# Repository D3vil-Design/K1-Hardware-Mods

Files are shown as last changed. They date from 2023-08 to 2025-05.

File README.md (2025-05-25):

# D3D K1 Hardware Modifications

This repository is dedicated to providing a centralized location to the hardware modifications that the D3vil Design team has created for the Creality K1 and K1 Max.

If you would like to support the team to fund future projects, you can visit us at our [Patreon](https://www.patreon.com/D3vilDesign). Thank you.

A tutorial for some of the WIP things here can be found at one of our D3vil Design team member's YouTube channel, Omranello: https://www.youtube.com/@omranello. Otherwise, **please refer to the respective README in each mod's folder.**

All work in this repository falls under the **Attribution-NonCommercial-ShareAlike 4.0 International (CC BY-NC-SA 4.0)** license unless mentioned otherwise.

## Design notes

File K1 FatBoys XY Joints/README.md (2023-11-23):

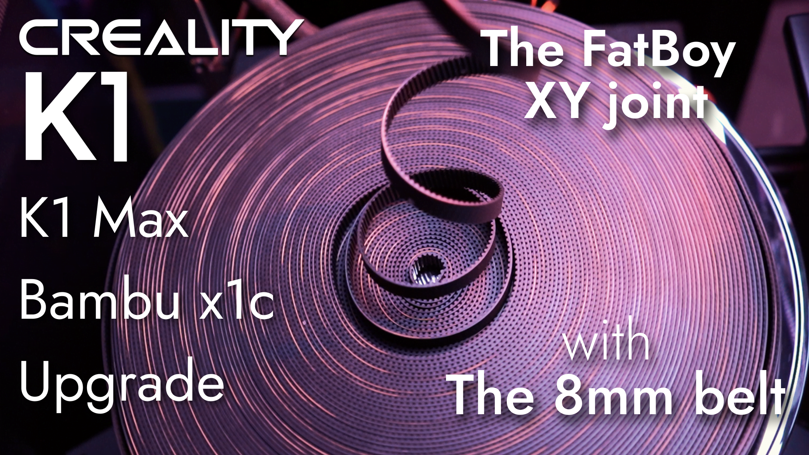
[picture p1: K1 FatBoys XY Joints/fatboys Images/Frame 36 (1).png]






Kindly if you dont know what you are doing , ask in our [Discord](https://discord.gg/d3vil-design) server

This joint are bigger by 5mm in both side which means it will reduce the overall X movment in the gantry on the K1 from 235 to 225 ( same build size ) 
- they can be used with the stock idlers ( if you are using the 8mm belt )
- or it can be used with any other 6mm idlers aswell.

Be advised to use the same M5x5mm grub screw to hold the rods in place instead of glue. (DO NOT OVERTIGHTEN)

changes might be needed to the printer.cfg file

For the K1:

change the [stepper_x] values below:

position_endstop: 226  ##stock value was 229

position_min: 0        ##stock value was -5

position_max: 226      ##stock value was 229

NOTE: the idea is to move you toolhead to X=10 and test move it from there 1mm at a time to see where the x carriage will touch the left XY joint.

For the K1 Max:

Needs to bee tested step by step ... will be updated

This will be updated soon™️

special thanks to all the ones who tested it and reported thier findings 

If you would like to support the team to fund future projects, you can visit us at our [Patreon](https://www.patreon.com/D3vilDesign).

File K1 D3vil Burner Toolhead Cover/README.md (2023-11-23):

# D3D K1 D3vil Burner V3

**The long awaited D3vil Burner by the D3D team, featuring Knomi support, is here!**

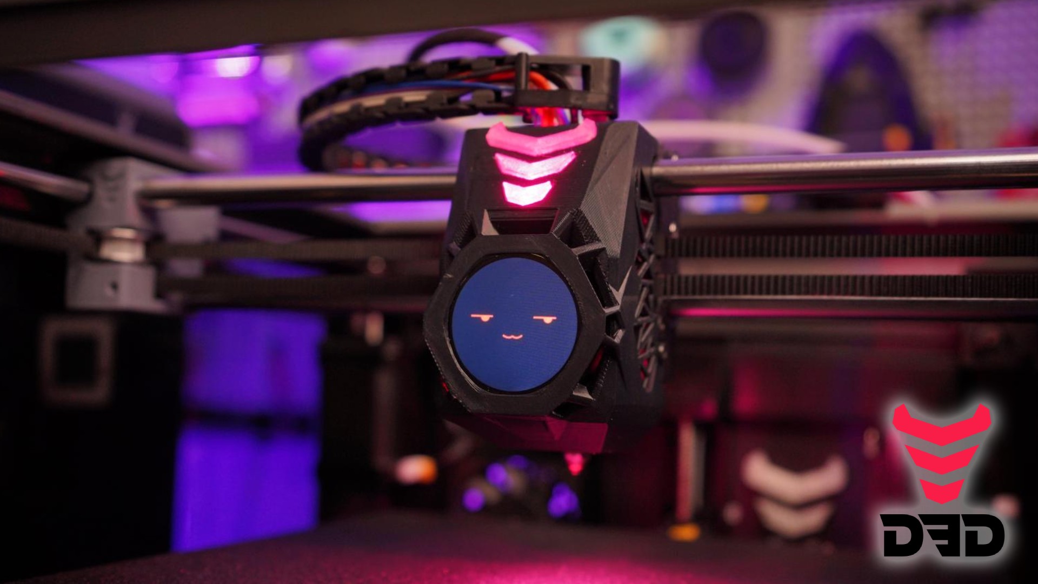
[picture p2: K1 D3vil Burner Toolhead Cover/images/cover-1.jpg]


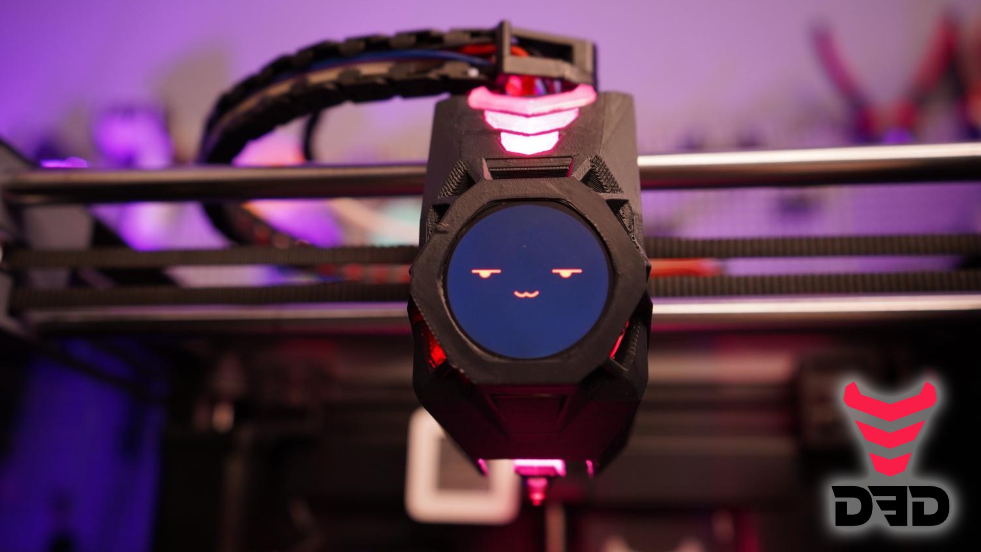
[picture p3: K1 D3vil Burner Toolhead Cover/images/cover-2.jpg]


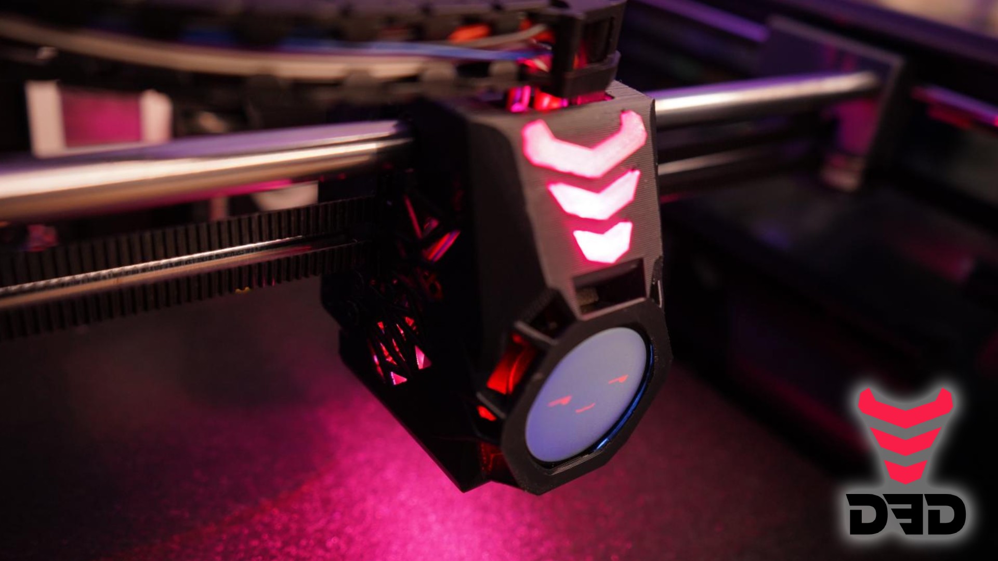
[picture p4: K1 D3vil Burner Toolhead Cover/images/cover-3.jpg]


## Introduction

D3vil Design is proud to release the D3vil Burner toolhead cover for the Creality K1 for **free**. Packed with features, the team has worked meticulously to make sure that the cover is ready for release and as easy as a drop-in as possible with the limited space in the stock Creality K1 toolhead setup.

## Features

- Drop in replacement for the Creality K1 - no permenant modifications!
- Full Knomi support - view print progress real time, and add a little flair to your toolhead!
- Customizable LED featuring the D3vil Design logo - use any LED to match the style of your setup!
- Lightweight - 3.5 grams **LIGHTER** than the stock toolhead! (tests using ASA/ABS+, stock K1 shroud at 23.8 grams, D3vil Burner printed in ASA is 20.3 grams)

## Support

Join our [Discord](https://discord.gg/d3vil-design) to chat with the team and find support for this product and anything else that D3D puts out :)

## Knomi 

for those who asked, you can purchase Knomi directly from the (non affiliate) link below 
https://biqu.equipment/collections/lcd/products/bigtreetech-knomi-v1-0

## Installation Guide

1. Download and print both STLs in this folder - the toolhead cover and the D3D logo. Recommended print settings for each are as follows:

   ##### D3vil Burner Toolhead Cover

   - Material: ABS, ASA, or another heat-resistant material
   - Layer Height: 0.2
   - Line width: 0.4
   - Walls: 3
   - Top/Bottom Layers: 3
   - Supports required (Top Z distance somewhere around 0.15)
   - orientation: print it facing up for the best results. 
   - Color: Your Choice!

   ##### D3vil Burner D3D Logo

   - Material: ABS, ASA, PETG, or another heat-resistant material
   - Layer Height: 0.2
   - Line width: 0.4
   - Walls: 3
   - Top/Bottom Layers: 3
   - Supports required (Top Z distance somewhere around 0.15)
   - Color: White or Transparent (we want light to shine through)

2. Remove the two screws from the stock toolhead cover and slide the cover off
3. Disconnect the front fan from the toolhead board and remove the fan from the stock toolhead cover
4. Slide the D3D Logo piece into the slot on the new toolhead's slot.
5. Connect a wire to the Knomi:

   ##### If you're not using an LED:

   5a. Find or create an MX1.25 (2pin) to MX1.25 (3pin) wire. Red to red, black to black according to the pinout shown on the board itself (Red to V and Black to G). We won't use the 3rd pin - this is just so we can connect it easily.

   5b. Connect the MX1.25 2pin to the Knomi **AND GENTLY PRY OFF THE USB PORT FROM THE KNOMI. IT DOES NOT FIT IN A STOCK SETUP**, then GENTLY (do not force, you'll crack the screen!) slide the Knomi into it's place from the back in.

   ##### If you are using an LED:

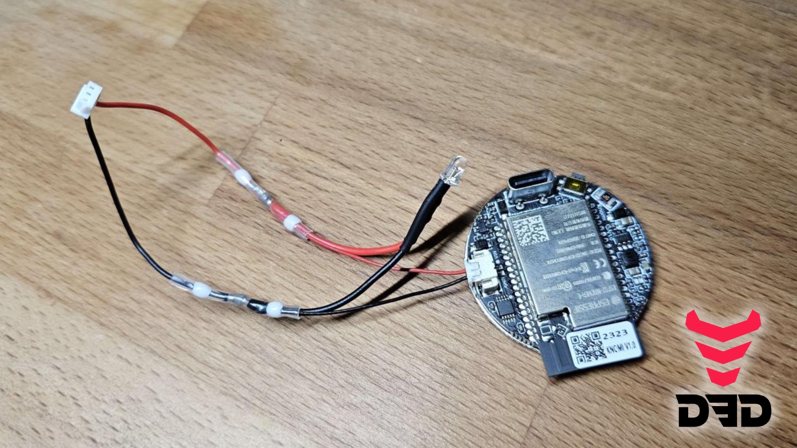
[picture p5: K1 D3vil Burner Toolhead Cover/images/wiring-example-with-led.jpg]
   

   5a. Create a three-way wire. This wire should be an MX1.25 (2pin) to MX1.25 (3pin) to V/G (whatever your LED needs) wire. Red to red to read, black to black to black according to the pinout shown on the board itself (Red to V and Black to G). We won't use the 3rd pin - this is just so we can connect it easily.

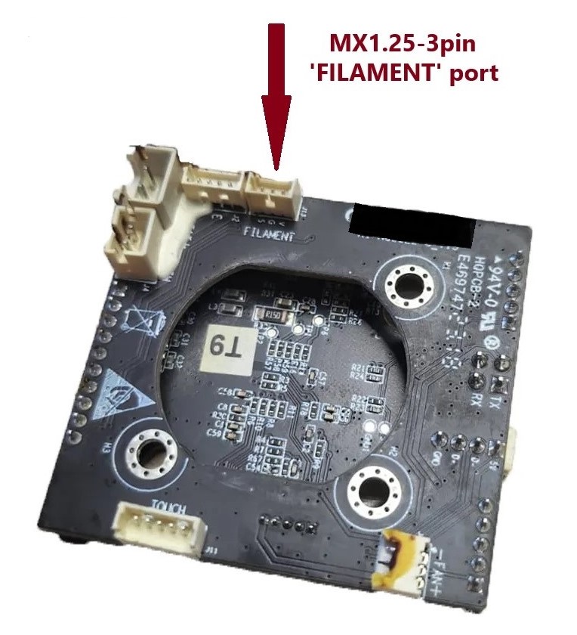
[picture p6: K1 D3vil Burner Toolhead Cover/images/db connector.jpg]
    

   5b. Solder or attach your V/G to your LED - the voltage is 5V coming from the toolboard - make sure your LED supports this or use a resistor.

   5c. There are two slots where you can lay your wires to prop up the LED. Attach those and prop your LED against the D3D logo piece.

   5d. Connect the MX1.25 2pin to the Knomi **AND GENTLY PRY OFF THE USB PORT FROM THE KNOMI. IT DOES NOT FIT IN A STOCK SETUP**, then GENTLY (do not force, you'll crack the screen!) slide the Knomi into it's place from the back in.

7. Slide the fan against the Knomi and attach the fan using the stock screws.
8. Connect the other end of the Knomi wire to the free filament sensor port on the toolhead board (again, outlined on the pinout shown on the board, Red to V and Black to G).
9. Re-attach the fan wire to the toolhead board.
10. Slide the D3vil Burner on to the toolhead and re-attach using the stock screws.
11. Voíla! Re-run input shaping, connect your Knomi following [BTT's instructions](https://github.com/bigtreetech/KNOMI/blob/master/KNOMI_USER_GUIDE.pdf).
12. NOTE: When connecting to Knomi Via wifi, in the setup screen, you will have to Add the IP address of your Printer ( Since this only works with Rooted Printers ) you will have to add the IP and the Port (ex: 192.168.1.10:4408 ).

And you're set!

If you would like to support the team to fund future projects, you can visit us at our [Patreon](https://www.patreon.com/D3vilDesign). We will begin posting behind the scenes projects, beta access to projects in flight, and more exclusively for our [Patreon](https://www.patreon.com/D3vilDesign) supporters.

-----------
If you wish to activate the Homing Macro please check the update below 

Thanks to [nephilim667](https://github.com/nephilim667)

[Homing macro fix](https://github.com/D3vil-Design/K1-Hardware-Mods/issues/4)

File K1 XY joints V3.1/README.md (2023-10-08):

# D3D K1 XY Joint V3.3 "Updated"

## NOTE:
YOU NEED TO REPRINT XY joint V3.3DD both right and left STL files since V3.1 had some tolerances issues .

# D3D K1 XY Joint V3.1

**This is a work in progress.**

To see how this was made and used, please watch the following video:

https://youtu.be/I9yJWq1kYok

This design was made to change the idlers in the K1 to a 6mm x 4mm bore or keep the original ones. For the idlers, we removed the pins and installed BHCS or SHCS M4x20mm... 18mm can also be used.

(Note in the setup shown above, we used M4x20 grub screws instead of a SHCS or BHCS) For the X axis rods, I used M5x5mm grub screws.

## print 

- ABS+,ASA ... OR WHAT U SEE FIT 
- 4 walls
- 4 bottom layers , 4 top layers
- 40% infill triangle
- orientation: Face(logo) down .
- with support

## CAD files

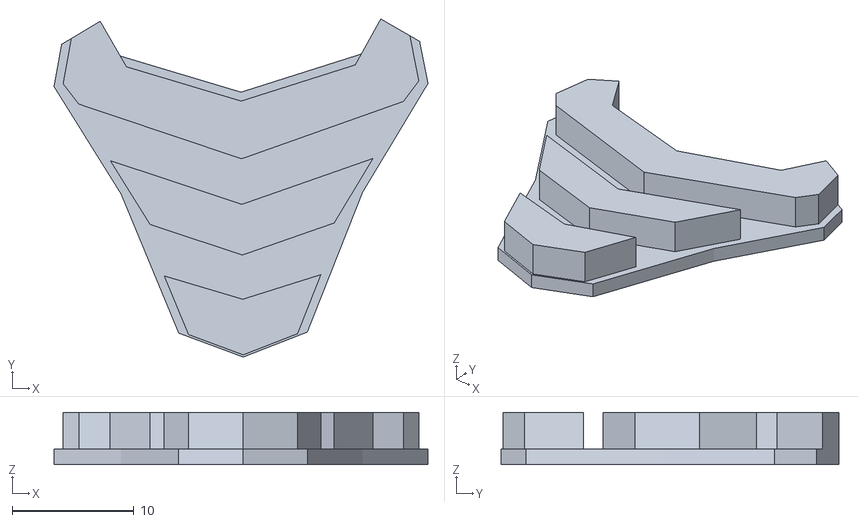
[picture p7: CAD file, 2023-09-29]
K1 D3vil Burner Toolhead Cover/K1 D3vil Burner Logo V3 (D3D).stl
30.8 x 27.8 x 4.30

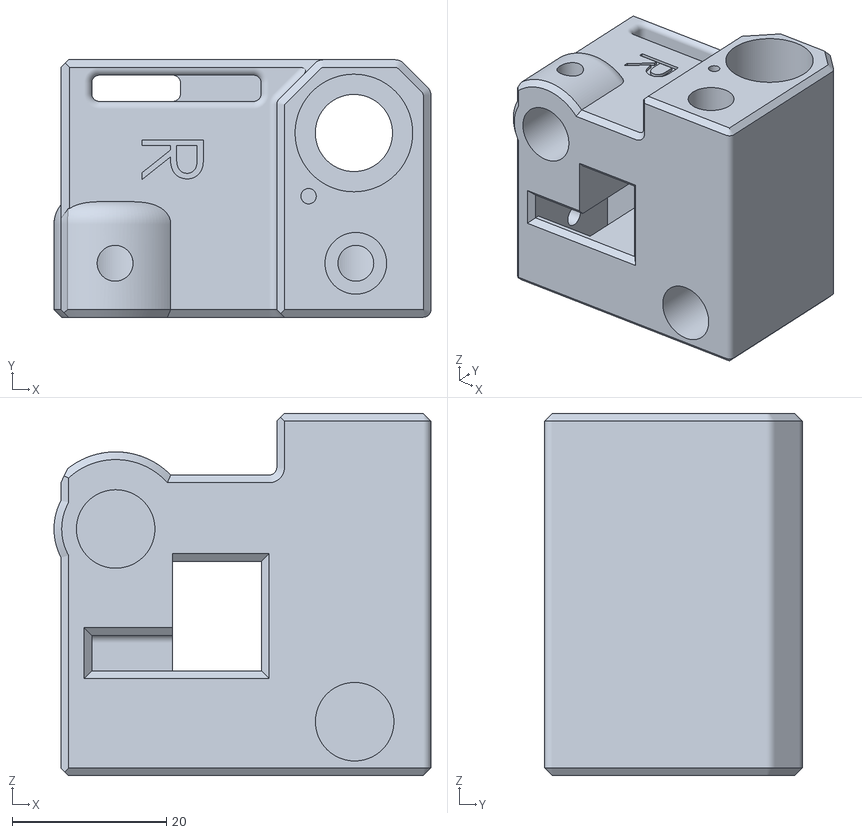
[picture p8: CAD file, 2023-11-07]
K1 FatBoys XY Joints/FatBoy XY joint R.stl
48.9 x 33.4 x 47.0

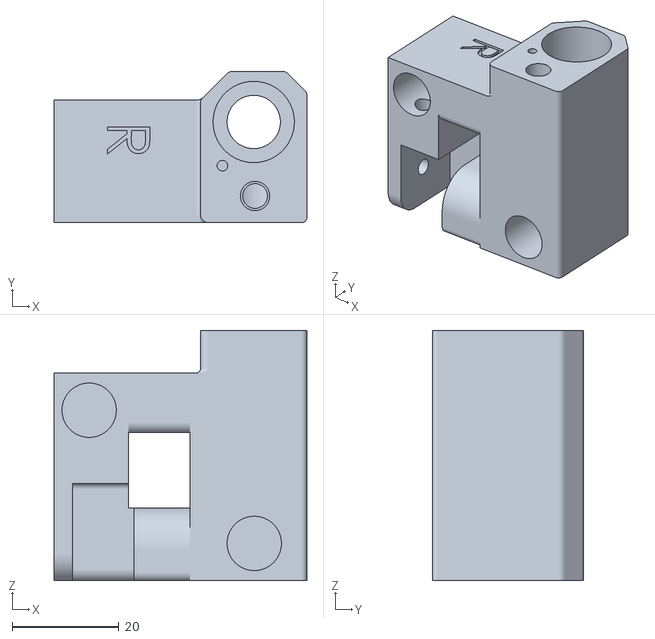
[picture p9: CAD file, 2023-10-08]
K1 XY joints V3.1/Right XY joint v3.3DD.stl
47.5 x 28.4 x 47.0

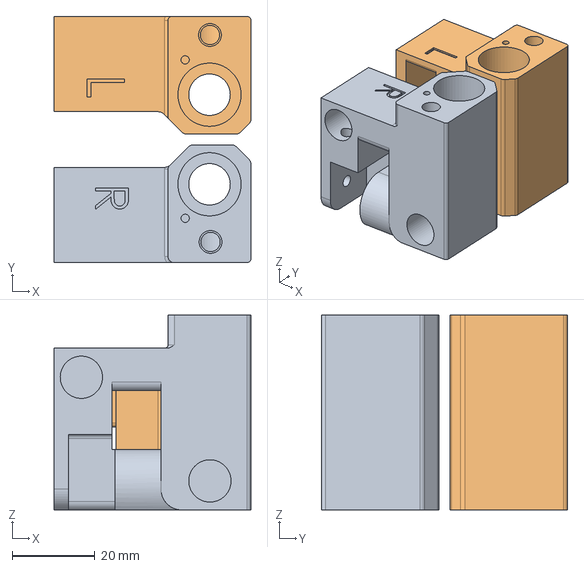
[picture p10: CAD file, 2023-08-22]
K1 XY joints V3.1/K1 XY JOINT V3 (D3D).step
47.5 x 59.4 x 47.0 mm
XY_joint_Right.STEP
XY_joint_Left.STEP

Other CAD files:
K1 FatBoys XY Joints/FatBoy XY joint L.stl
K1 XY joints V3.1/Left XY joint v3.3DD.stl
K1 XY joints V3.1/K1 XY Joint V3 (D3D).3mf

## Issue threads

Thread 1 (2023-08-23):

"k1 xy joint v3.1.3mf" being flagged as Archive.Bomb by Baidu in VirusTotal

Su-Plx, 2023-08-23:
Hi Omran!

First off, thank you so much for all the assistance you've been offering the K1 community---I know that I, and a lot of other folks who have bought one, have honestly felt more supported and seen in the tutorial and mod videos that you've made, than by the support offered from Creality themselves. It can often be thankless, and dealing with Creality can be incredibly frustrating, so I want you to know that, at least for me, your videos are the ones I go to first whenever I'm having trouble with the printer, need to remember how something was put together, get ideas for improvements, etc.. And the music isn't bad, either 😎️👍️

The work you've put into refining the movement system is the first major step forward into making the K1 a truly consistent and reliable print platform. Thank you so much!

I wanted to give you a heads up that for whatever reason, Baidu via VirusTotal is flagging the file "k1 xy joint v3.1.3mf" as an archive/zip bomb. I grabbed a couple random 3mf files from Printables with a similar size/number of compressed files, and scanned them to see if Baidu was flagging all 3mf files, but I only saw that behavior from the 3mf I got from your github repo.

I don't think it is intentional, and haven't flagged or reported the file to github or anything. My guess is that the easiest fix might be to try repacking the model into a new 3mf and re-uploading, but I'm not set up to test that sort of thing, so I can't say for sure.

Thank you again for the incredible help you've been to the K1 community!

-Su_Plx

Omranello, 2023-08-23:
Bro thanks alot for the sweet email , this worth it all.

I will upload the STL instead .. it's better I guess.

Thanks for the heads up,  I would not have noticed it myself.

If anything I can help u with please contact me ... always here to help .

Thanks again

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

Omranello, 2023-10-09:
New files uploaded .

Closed 2023-10-09.

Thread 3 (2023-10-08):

knomi issues

kwotattoos, 2023-10-08:
in the read me it says to follow btt info for the knomi but the required macro gave me errors and locked up my homing. what should we add to get the knomi to show all the different animations?

Omranello, 2023-10-09:
> in the read me it says to follow btt info for the knomi but the required macro gave me errors and locked up my homing. what should we add to get the knomi to show all the different animations?

The Macros are not needed , (only for homing and leveling animation /information)
Once the Knomi is linked fine wifi thro the Hello screen by adding the ( IP address: port ) all should work fine.

lvlacleod, 2023-10-09:
> in the read me it says to follow btt info for the knomi but the required macro gave me errors and locked up my homing. what should we add to get the knomi to show all the different animations?

To get Homing and bed mesh working follow this. Took me a while to figure it all out but finally got both homing and bed mesh working with knomi.
https://github.com/bigtreetech/KNOMI/pull/5

Omranello, 2023-11-01:
Thank you , ill go ahead and close this as we will add it to the main page

Closed 2023-11-01.

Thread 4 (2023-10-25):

Macro integration for Homing and Leveling

nephilim667, 2023-10-25:
Hello,

I have integrated a Knomi from BigTreeTech with your D3vil design head mount.

Actually in Knomi documentation they tell to add relevant macros for homing and bed leveling.
Unfortunatly those macro aren't working on K1 !

After some research i have finally make it work.

for homing, if you put macro as it, it will throw an error 'G28 is called recursively'.
I have found that come from macro defined in sensorless.cfg

So to make it work, first add the macro at end of file
`[gcode_macro G28]`
`rename_existing: G0028`
`variable_homing:False`
`gcode:`
`  RESPOND TYPE=command MSG='Custom G28 called'`
`  SET_GCODE_VARIABLE MACRO=G28 VARIABLE=homing VALUE=True`
`  G0028 {rawparams}`
`  SET_GCODE_VARIABLE MACRO=G28 VARIABLE=homing VALUE=False`

atfer what find _HOME_X, _HOME_Y and _HOME_Z macro and replace G28 in it by G0028 like this
`[gcode_macro _HOME_X]`
`gcode:`
`  _IF_MOVE_XY`
`  {% if printer['gcode_macro xyz_ready'].x_ready|int == 1 %}`
`    {% if (printer.configfile.settings['stepper_x'].position_max - printer.toolhead.position.x)|round < 10 %}`
`      {% set x_park = (10 - (printer.configfile.settings['stepper_x'].position_max - printer.toolhead.position.x))|round %}`
`      {% if x_park > 0 %}`
`        G91`
 `       G1 x-{x_park} F3600`
`        G90`
`        G4 P1000`
`      {% endif %}`
`    {% endif %}`
`  {% endif %}`
`  `
`# SET_TMC_FIELD FIELD=SGTHRS STEPPER=stepper_y VALUE=70`
`# SET_TMC_FIELD FIELD=SGTHRS STEPPER=stepper_x VALUE=70`
`# Home`
`  RESPOND TYPE=command MSG='Call G28 in _HOME_X macro'`
`  G0028 X #<<====== HERE`
`  SET_GCODE_VARIABLE MACRO=xyz_ready VARIABLE=x_ready VALUE=1`
`# Move away`
`  G91`
`  G1 x-10 F3600`
`  G90`
`# Wait just a second (give StallGuard registers time to clear)`
` G4 P2000`

For bed leveling, as i'm using Kamp, in Adaptative_Meshing.cfg, BED_MESH_CALIBRATE Macro is already defined
So just add  "variable_probing:False" after rename existing and SET_GCODE_VARIABLE before and after calling _BED_MESH_CALIBRATE

Here is the modified macro :
`[gcode_macro BED_MESH_CALIBRATE]`
`rename_existing: _BED_MESH_CALIBRATE`
`variable_probing:False`
`gcode:`

    {% set all_points = printer.exclude_object.objects | map(attribute='polygon') | sum(start=[]) %}                                # Gather all object points
    {% set bed_mesh_min = printer.configfile.settings.bed_mesh.mesh_min %}                                                          # Get bed mesh min from printer.cfg
    {% set bed_mesh_max = printer.configfile.settings.bed_mesh.mesh_max %}                                                          # Get bed mesh max from printer.cfg
    {% set probe_count = printer.configfile.settings.bed_mesh.probe_count %}                                                        # Get probe count from printer.cfg
    {% set kamp_settings = printer["gcode_macro _KAMP_Settings"] %}                                                                 # Pull variables from _KAMP_Settings
    {% set verbose_enable = kamp_settings.verbose_enable | abs %}                                                                   # Pull verbose setting from _KAMP_Settings
    {% set probe_dock_enable = kamp_settings.probe_dock_enable | abs %}                                                             # Pull probe dockable probe settings from _KAMP_Settings
    {% set attach_macro = kamp_settings.attach_macro | string %}                                                                    # Pull attach probe command from _KAMP_Settings
    {% set detach_macro = kamp_settings.detach_macro | string %}                                                                    # Pull detach probe command from _KAMP_Settings
    {% set mesh_margin = kamp_settings.mesh_margin | float %}                                                                       # Pull mesh margin setting from _KAMP_Settings
    {% set fuzz_amount = kamp_settings.fuzz_amount | float %}                                                                       # Pull fuzz amount setting from _KAMP_Settings
    {% set probe_count = probe_count if probe_count|length > 1 else probe_count * 2  %}                                             # If probe count is only a single number, convert it to 2. E.g. probe_count:7 = 7,7
    {% set max_probe_point_distance_x = ( bed_mesh_max[0] - bed_mesh_min[0] ) / (probe_count[0] - 1)  %}                            # Determine max probe point distance
    {% set max_probe_point_distance_y = ( bed_mesh_max[1] - bed_mesh_min[1] ) / (probe_count[1] - 1)  %}                            # Determine max probe point distance
    {% set x_min = all_points | map(attribute=0) | min | default(bed_mesh_min[0]) %}                                                # Set x_min from smallest object x point
    {% set y_min = all_points | map(attribute=1) | min | default(bed_mesh_min[1]) %}                                                # Set y_min from smallest object y point
    {% set x_max = all_points | map(attribute=0) | max | default(bed_mesh_max[0]) %}                                                # Set x_max from largest object x point
    {% set y_max = all_points | map(attribute=1) | max | default(bed_mesh_max[1]) %}                                                # Set y_max from largest object y point

    {% set fuzz_range = range((0) | int, (fuzz_amount * 100) | int + 1) %}                                                          # Set fuzz_range between 0 and fuzz_amount
    {% set adapted_x_min = x_min - mesh_margin - (fuzz_range | random / 100.0) %}                                                   # Adapt x_min to margin and fuzz constraints
    {% set adapted_y_min = y_min - mesh_margin - (fuzz_range | random / 100.0) %}                                                   # Adapt y_min to margin and fuzz constraints
    {% set adapted_x_max = x_max + mesh_margin + (fuzz_range | random / 100.0) %}                                                   # Adapt x_max to margin and fuzz constraints
    {% set adapted_y_max = y_max + mesh_margin + (fuzz_range | random / 100.0) %}                                                   # Adapt y_max to margin and fuzz constraints

    {% set adapted_x_min = [adapted_x_min , bed_mesh_min[0]] | max %}                                                               # Compare adjustments to defaults and choose max
    {% set adapted_y_min = [adapted_y_min , bed_mesh_min[1]] | max %}                                                               # Compare adjustments to defaults and choose max
    {% set adapted_x_max = [adapted_x_max , bed_mesh_max[0]] | min %}                                                               # Compare adjustments to defaults and choose min
    {% set adapted_y_max = [adapted_y_max , bed_mesh_max[1]] | min %}                                                               # Compare adjustments to defaults and choose min

    {% set points_x = (((adapted_x_max - adapted_x_min) / max_probe_point_distance_x) | round(method='ceil') | int) + 1 %}          # Define probe_count's x point count and round up
    {% set points_y = (((adapted_y_max - adapted_y_min) / max_probe_point_distance_y) | round(method='ceil') | int) + 1 %}          # Define probe_count's y point count and round up

    {% if (points_x > points_y) %}
        {% set points_y = points_x %}
    {% endif %}

    {% if (points_x < points_y) %}
        {% set points_x = points_y %}
    {% endif %}

    {% if (([points_x, points_y]|max) > 6) %}                                                                                       #
        {% set algorithm = "bicubic" %}                                                                                             #
        {% set min_points = 4 %}                                                                                                    #
    {% else %}                                                                                                                      # Calculate if algorithm should be bicubic or lagrange
        {% set algorithm = "lagrange" %}                                                                                            #
        {% set min_points = 3 %}                                                                                                    #
    {% endif %}                                                                                                                     #

    {% set points_x = [points_x , min_points]|max %}                                                                                # Set probe_count's x points to fit the calculated algorithm
    {% set points_y = [points_y , min_points]|max %}                                                                                # Set probe_count's y points to fit the calculated algorithm
    {% set points_x = [points_x , probe_count[0]]|min %}
    {% set points_y = [points_y , probe_count[1]]|min %}

    {% if verbose_enable == True %}                                                                                                 # If verbose is enabled, print information about KAMP's calculations
        {% if printer.exclude_object.objects != [] %}

            { action_respond_info( "Algorithm: {}.".format(                                                                      
                (algorithm),                                                                                                    
            )) }

            { action_respond_info("Default probe count: {},{}.".format(                                                          
                (probe_count[0]),                                                                                               
                (probe_count[1]),                                                                                               
            )) }

            { action_respond_info("Adapted probe count: {},{}.".format(                                                          
                (points_x),                                                                                                     
                (points_y),                                                                                                     
            )) }
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
Omranello, 2023-10-25:
Someone reported the Same , thanks for sharing , will try to test it and update the page . 🙏

nephilim667, 2023-10-26:
you're welcome !
thanks to you to share your awesome desing to integrate a knomi on K1 !

Omranello, 2023-11-01:
ill go ahead and close this, and will try to add your code to the main page. Thanks again.

Nazgile94, 2023-11-25:
worked, thanks!

Galv87, 2023-12-17:
my Kamp files are read only so i can't add the homing, is anyone else having this issue?

nephilim667, 2023-12-17:
yes, since guillouz have change the script and make Kamp file readonly, you have to edit in in SSH mode with nano in sudo mode.

Galv87, 2023-12-17:
> yes, since guillouz have change the script and make Kamp file readonly, you have to edit in in SSH mode with nano in sudo mode.

what's the initial code to put into terminal (I'm a noob with terminal) ill that edit the file to take it out of read only?

nephilim667, 2023-12-20:
you can find an help guide i have made here
https://docs.google.com/document/d/13aPvhx-T9cJWjTx8hVB9-xSNzAWho6zwdE2oVVuJMIU/edit?usp=drive_link

this guide is to help with Guillouz script, but at the end you will find the integration of knomi macro with nano.
Hope this can help

Barconero, 2024-09-21:
Hi!

Is this mean, that we do not need to change Adaptative_Meshing.cfg at all, evrything is done in knomi.cfg, yes?

Closed 2023-11-01.

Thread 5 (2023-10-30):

Bearings

bronsn, 2023-10-30:
Hello,
great work from you and your Team/Partner what ever , glad that you give us such good impressions and information about the K1.
I have damaged my Bearing above the big idler over the Stepper motor , so i stopped the work and put the damaged back (he works but i think he will break soon ), do you know wich bearings are there in or which number they have ?

Other i have to disamble the printer again before i can purchase some new one.
Sry i know this is not the Issue with your design as itself, but perhaps you can help me :)

Regards

DerrickDarrell, 2023-10-30:
youre talking about the bearing on the stepper shaft?

bronsn, 2023-10-30:
yes )

Omranello, 2023-11-01:
kindly do join our discord for those related issues . https://discord.gg/vPr5DjfHUJ

Closed 2023-11-01.

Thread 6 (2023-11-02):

Gantry V2.0

sbtoonz, 2023-11-02:
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
Cant print the idlers are floating in midair

Can  you potentially re up with them all split?

sbtoonz, 2023-11-02:
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
part is mis organized in the STL on git

DerrickDarrell, 2023-11-02:
right click>split to objects

Closed 2023-11-07.

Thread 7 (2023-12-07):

How about adapating A new motherboard for Vanilla Klipper

sismo99, 2023-12-07:
How about adapting a new motherboard to be able to use Klipper Vanilla, I was thinking about one from Big Tree Tech, specifically a Manta 5P and using a 5-inch BTT SPI (or even HDMI) screen to use Klipperscreen. I have been analyzing the original motherboard but the CANBus parts and the Strain gauges are complicated for me. I hope you can help me.

sbtoonz, 2023-12-14:
> How about adapting a new motherboard to be able to use Klipper Vanilla, I was thinking about one from Big Tree Tech, specifically a Manta 5P and using a 5-inch BTT SPI (or even HDMI) screen to use Klipperscreen. I have been analyzing the original motherboard but the CANBus parts and the Strain gauges are complicated for me. I hope you can help me.

Visit our discord for more

I have this operating as you describe

https://github.com/sbtoonz/k1_klipper

repo I am operating my m5p k1 off of

Closed 2024-03-08.

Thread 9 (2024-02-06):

Filment Port Power

FunkoTalkz, 2024-02-06:
How do i go about getting power from the "FILMENT" port on toolhead.

DerrickDarrell, 2024-02-06:
Im guessing this is regarding the knomi shroud? Please read the installation guide

Closed 2024-03-08.

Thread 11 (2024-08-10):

Knomi v2 bed leveling on K1 series

killergreenx420, 2024-08-10:
there is a easier way to fix the bed leveling I looked at what had previously been added to fix it and found that it was overly complicated the Knomi_v2.cfg it changes the G28 macro to G28.1 so all that is needed to fix the K1 error is to open sensorless.cfg go to Home X, Home Y, and Home Z and in each macro change G28 line to G28.1 that's it and it fixes the issue you can copy or look at what's needed to be changed
#<-----This is what changes for Knomi v2 is shown on the line that needs changed but this is a easy fix and the other way had you add a macro and change quite a few things this requires  3 changes

[gcode_macro _HOME_X]
gcode:
  _IF_MOVE_XY

  {% if printer['gcode_macro xyz_ready'].x_ready|int == 1 %}
    {% if (printer.configfile.settings['stepper_x'].position_max - printer.toolhead.position.x)|round < 10 %}
      {% set x_park = (10 - (printer.configfile.settings['stepper_x'].position_max - printer.toolhead.position.x))|round %}
      {% if x_park > 0 %}
        G91
        G1 x-{x_park} F3600
        G90
        G4 P1000
      {% endif %}
    {% endif %}
  {% endif %}

  # SET_TMC_FIELD FIELD=SGTHRS STEPPER=stepper_y VALUE=70
  # SET_TMC_FIELD FIELD=SGTHRS STEPPER=stepper_x VALUE=70
  # Home
  G28.1 X      #<-----This is what changes for Knomi v2
  SET_GCODE_VARIABLE MACRO=xyz_ready VARIABLE=x_ready VALUE=1
  # Move away
  G91
  G1 x-10 F3600
  G90
  # Wait just a second (give StallGuard registers time to clear)
  G4 P2000

[gcode_macro _HOME_Y]
gcode:
  _IF_MOVE_XY

  {% if printer['gcode_macro xyz_ready'].y_ready|int == 1 %}
    {% if printer.toolhead.position.y|round < 9 %}
      {% set y_park = 9 - printer.toolhead.position.y|round %}
      {% if y_park > 0 %}
        G91
        G1 y{y_park} F3600
        G90
        G4 P1000
      {% endif %}
    {% endif %}
  {% endif %}

  # SET_TMC_FIELD FIELD=SGTHRS STEPPER=stepper_y VALUE=60
  # SET_TMC_FIELD FIELD=SGTHRS STEPPER=stepper_x VALUE=60
  # Home
  G28.1 Y        #<-----This is what changes for Knomi v2
  SET_GCODE_VARIABLE MACRO=xyz_ready VARIABLE=y_ready VALUE=1
  # Move away
  G91
  G1 y10 F3600
  G90
  # Wait just a second (give StallGuard registers time to clear)
  G4 P2000

[gcode_macro _HOME_Z]
gcode:
  {% if printer['gcode_macro xyz_ready'].y_ready|int == 1 %}
    {% if printer['gcode_macro xyz_ready'].x_ready|int == 1 %}
      _IF_HOME_Z
    {% endif %}
  {% endif %}
  {% if printer.print_stats.z_pos|float >= 210.0 %}
    FORCE_MOVE STEPPER=stepper_z DISTANCE=-8 VELOCITY=10
  {% endif %}

  {% set POSITION_X = printer.configfile.settings['stepper_x'].position_max/2 %}
  {% set POSITION_Y = printer.configfile.settings['stepper_y'].position_max/2 %}
  # BED_MESH_SET_DISABLE
  G91
  {% set x_park = POSITION_X - printer.toolhead.position.x|int %}
  {% set y_park = POSITION_Y - printer.toolhead.position.y|int %}
  {action_respond_info("x_park = %s \n" % (x_park))}
  {action_respond_info("y_park = %s \n" % (y_park))}
  G1 x{x_park} y{y_park} F3600
  G90
  # G4 P500

  G28.1 Z     #<-----This is what changes for Knomi v2
  SET_GCODE_VARIABLE MACRO=xyz_ready VARIABLE=z_ready VALUE=1
  # BED_MESH_SET_ENABLE

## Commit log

2023-09-25 refine repo structure
    [K1 XY JOINT V3 (D3D).step, K1 XY Joint V3 (D3D).3mf]
2023-09-29 The K1 Devil Burner
    Instructions placed here ...
    [clear logo D3vil Burner D3D_V4.stl]
2023-09-29 add documentation and upload K1 D3vil Burner
    [K1 D3vil Burner Logo V3 (D3D).stl]
2023-10-08 Add files via upload
    Idler location have been adjusted with other tolerances.
    [Left XY joint v3.3DD.stl, Right XY joint v3.3DD.stl]
2023-10-08 Update V
    [Belt Tensioners.stl, Front Left Idler Mount.stl, Front Right Idler Mount.stl]
2023-10-31 Update README.md
    updated pulley measurements
2023-10-31 Update README.md
    updated print settings
2023-11-06 Name change
    [K1 5015 Bed Fan Mount Single.stl]
2023-12-23 Upload K1 TBGS-8mm Step Files
    [K1 TBGS-8mm Rods Concept Carriage.step, K1 TBGS-8mm Rods Concept Joints.step]
2023-12-23 Upload K1 Gantry V1 Step Files
    [Belt Tensioners.step, Front Left Idler Mount.step, Front Right Idler Mount.step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]
2023-12-23 Step files upload
    [Belt Tensioners.step, Belt Tensioners.stl, Front Left Idler Mount.step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]
